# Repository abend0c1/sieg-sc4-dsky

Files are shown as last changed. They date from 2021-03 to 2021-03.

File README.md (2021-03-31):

# SIEG SC4 Display and Keyboard (DSKY) Alternative
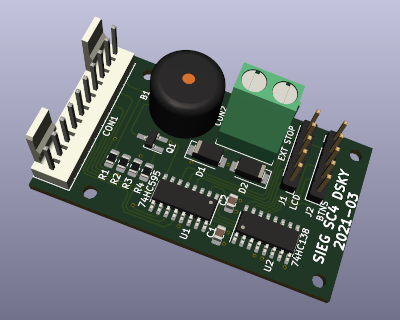
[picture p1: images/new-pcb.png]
PCB image


This is a replacement Printed Circuit Board (PCB) for the original Sieg SC4 lathe's
control panel. 

The intent is to replace the flat touch panel
buttons with regular illuminated push button switches that
are easier to use when the machine is in operation.

To do that, the original PCB must be removed as it gets in 
the way of the new panel switches. The LCD module on the
original PCB is retained by physically cutting it off 
with a utility knife and mounting it behind a new aluminium panel with a few
bolts and some J-B Weld epoxy.

The original panel looks like:

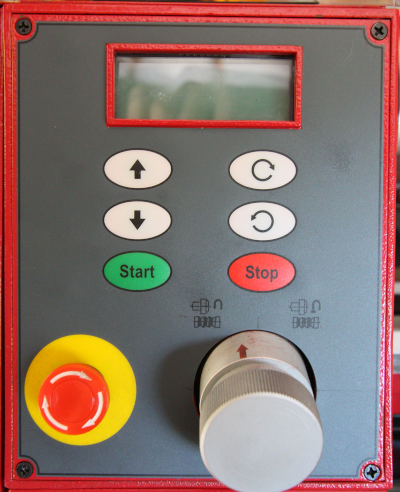
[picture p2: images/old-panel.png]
Old control panel image


The new panel has illuminated push button switches arranged
in a more intuitive way:

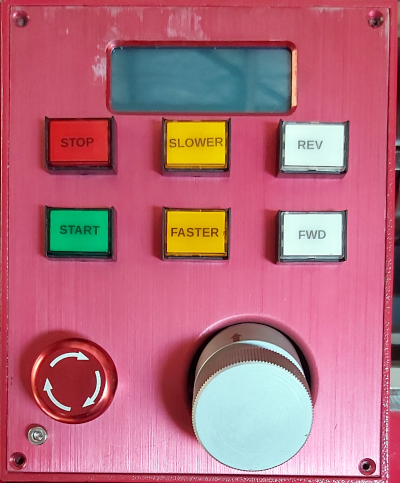
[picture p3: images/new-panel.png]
New control panel image


The connections that were made between the switches on the old PCB
are now made directly between the new switches using hookup wire.

The new PCB is considerably smaller because it does not
have to accommodate the old tactile switches. It can be
connected to the both LCD and switches using ribbon cable.

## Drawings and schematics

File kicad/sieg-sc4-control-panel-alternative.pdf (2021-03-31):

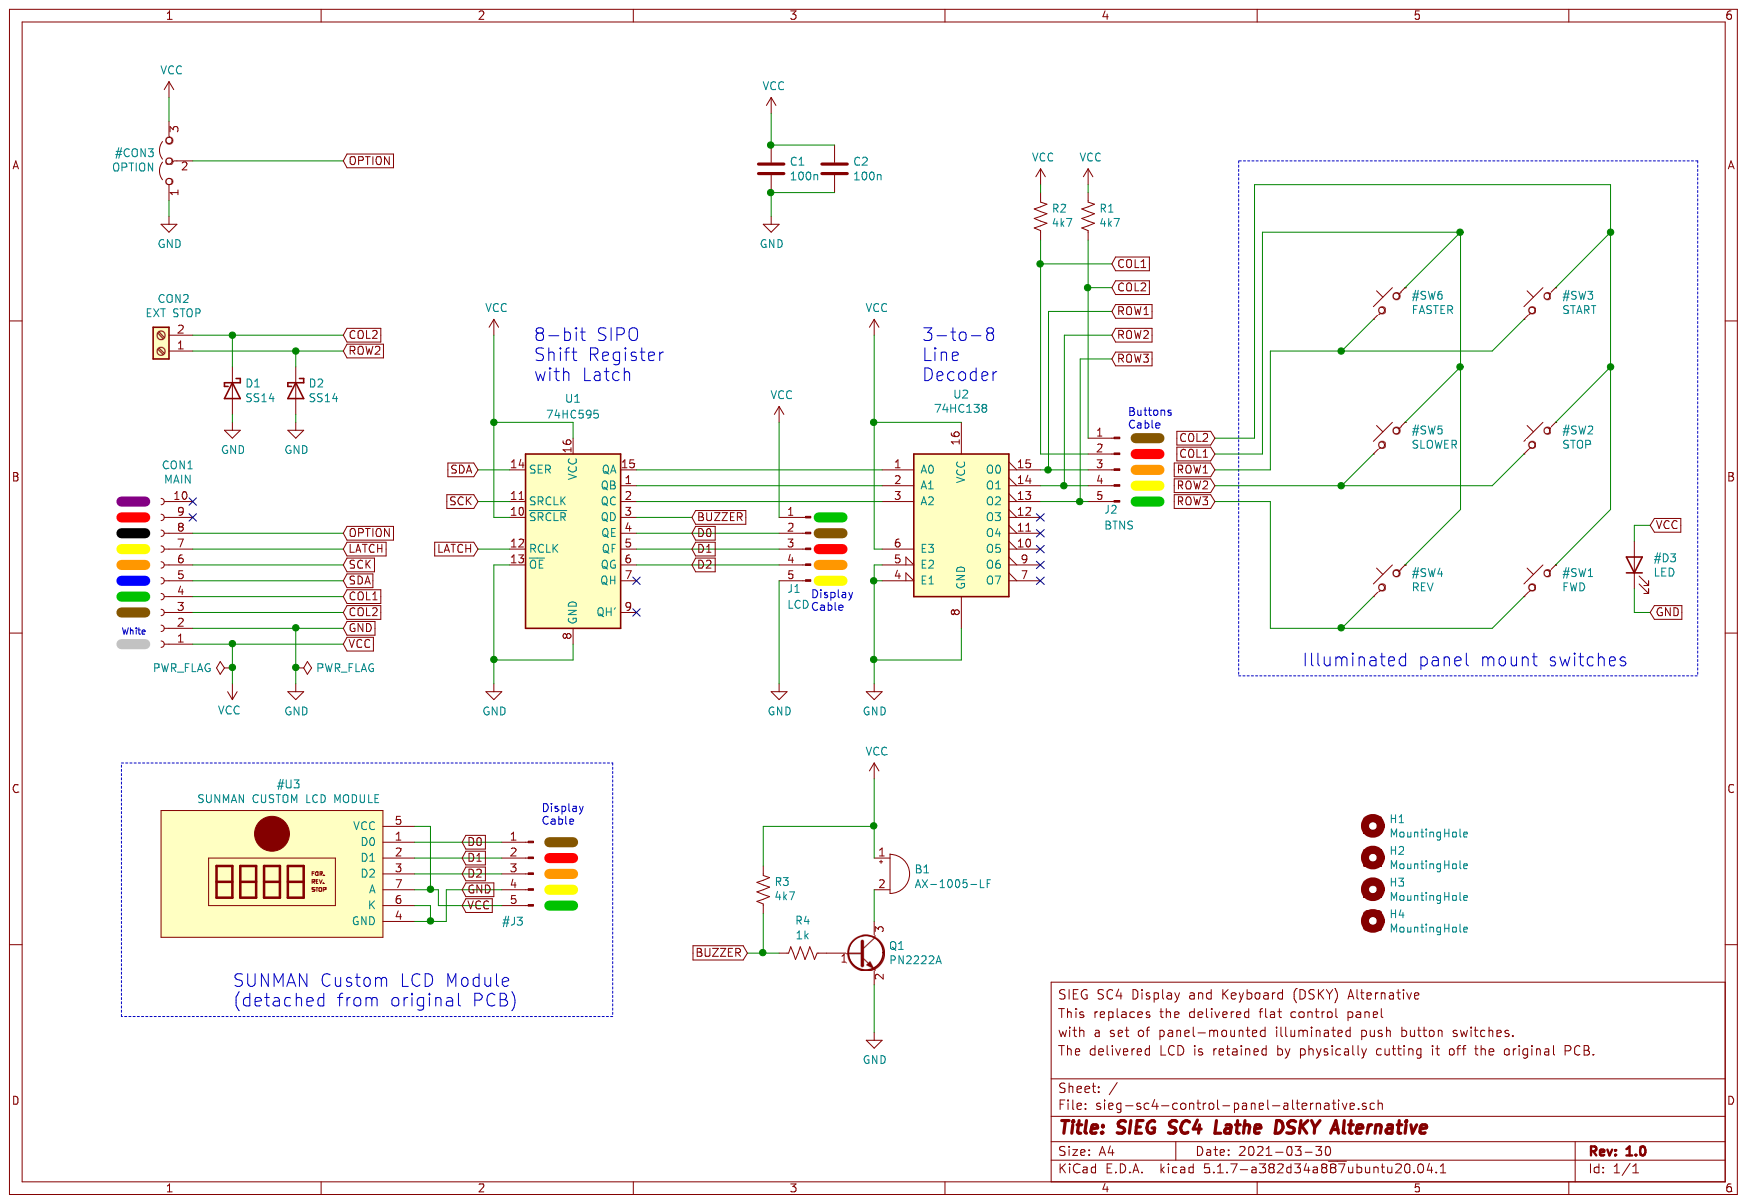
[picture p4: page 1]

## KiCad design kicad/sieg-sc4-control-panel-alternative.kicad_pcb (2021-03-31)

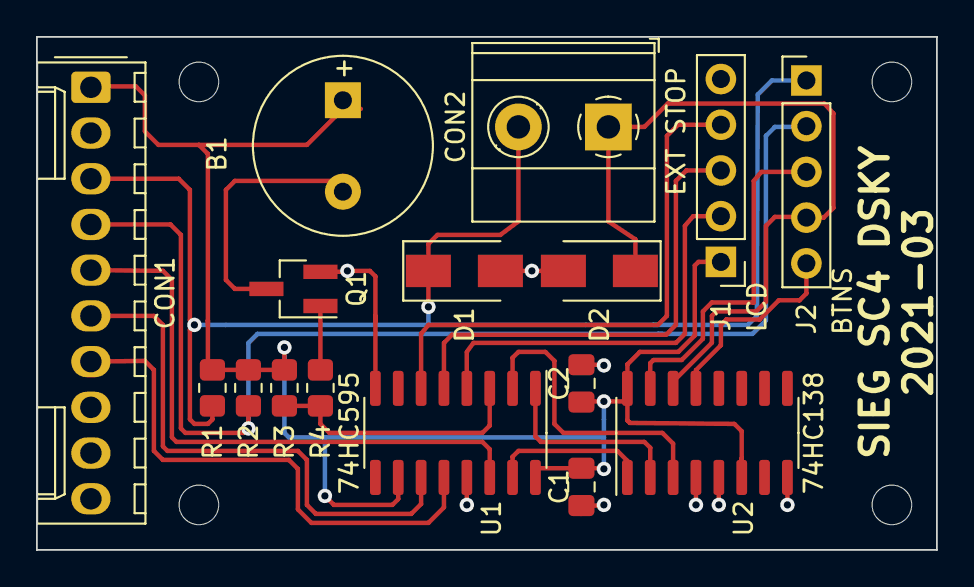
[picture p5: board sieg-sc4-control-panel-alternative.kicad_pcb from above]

Board: 2 copper layers, 50.0 x 28.5 mm, 20 parts (0 on the bottom side), 19 nets.

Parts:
B1: AX-1005-LF; Buzzer_9.6x5_P5
C1, C2: 100n; C_0805_2012Metric_Pad1.18x1.45mm_HandSolder
CON1: MAIN; Molex_KK-254_AE-6410-10A_1x10_P2.54mm_Vertical
CON2: EXT STOP; TerminalBlock_Phoenix_MKDS-1,5-2_1x02_P5.00mm_Horizontal
D1, D2: SS14; D_SMA
H1, H2, H3, H4: MountingHole; MountingHole_2.2mm_M2
J1: LCD; PinHeader_1x05_P2.54mm_Vertical
J2: BTNS; PinHeader_1x05_P2.54mm_Vertical
Q1: PN2222A; SOT-23_Handsoldering
R1, R2, R3: 4k7; R_0805_2012Metric_Pad1.20x1.40mm_HandSolder
R4: 1k; R_0805_2012Metric_Pad1.20x1.40mm_HandSolder
U1: 74HC595; SOIC-16_3.9x9.9mm_P1.27mm
U2: 74HC138; SOIC-16_3.9x9.9mm_P1.27mm

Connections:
BUZZER: R3.1, R4.2, U1.3
COL1: CON1.4, J2.2, R2.1
COL2: CON1.3, CON2.2, D1.1, J2.1, R1.1
D0: J1.2, U1.4
D1: J1.3, U1.5
D2: J1.4, U1.6
GND: C1.2, C2.2, CON1.2, D1.2, D2.2, J1.5, Q1.2, U1.8, U1.13, U2.4, U2.5, U2.8
LATCH: CON1.7, U1.12
unnamed: B1.2, Q1.3
unnamed: Q1.1, R4.1
unnamed: U1.1, U2.2
unnamed: U1.2, U2.3
unnamed: U1.15, U2.1
ROW1: J2.3, U2.15
ROW2: CON2.1, D2.1, J2.4, U2.14
ROW3: J2.5, U2.13
SCK: CON1.6, U1.11
SDA: CON1.5, U1.14
VCC: B1.1, C1.1, C2.1, CON1.1, J1.1, R1.2, R2.2, R3.2, U1.10, U1.16, U2.6, U2.16
